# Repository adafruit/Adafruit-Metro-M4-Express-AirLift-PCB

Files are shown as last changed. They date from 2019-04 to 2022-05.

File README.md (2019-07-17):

## Adafruit Metro M4 Express AirLift (WiFi) - Lite PCB

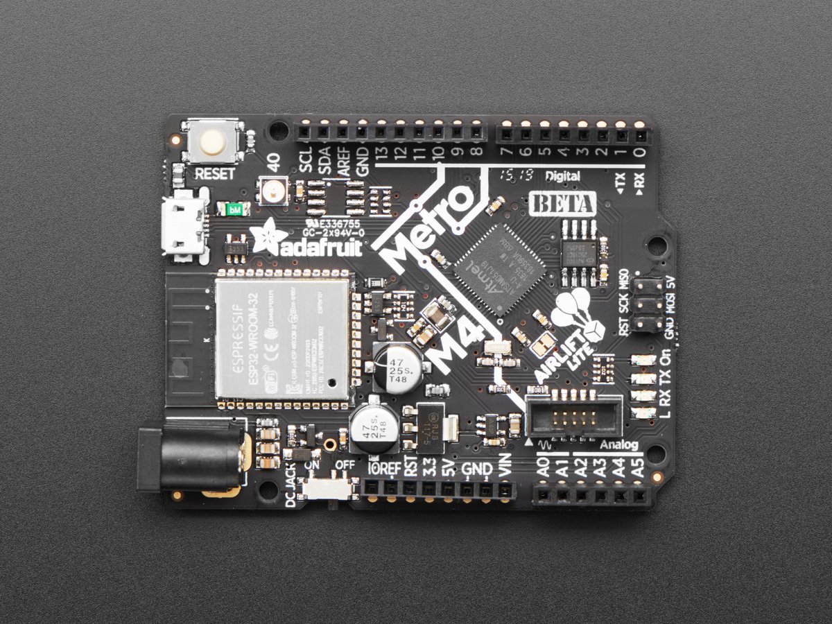
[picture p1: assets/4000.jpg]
<a href="http://www.adafruit.com/products/4000"><br/>
Click here to purchase one from the Adafruit shop</a>

PCB files for the Adafruit Metro M4 Express AirLift (WiFi) - Lite. 

Format is EagleCAD schematic and board layout
* https://www.adafruit.com/product/4000

### Description

Give your next project a lift with _AirLift_ - our witty name for the ESP32 co-processor that graces this Metro M4. You already know about the **Adafruit Metro M4** featuring the **Microchip ATSAMD51**, with it's 120MHz Cortex M4 with floating point support. With a train-load of FLASH and RAM, your code will be fast and roomy. And what better way to improve it than to add wireless? Now cooked in directly on board, you get a certified WiFi module that can handle all your TLS and socket needs, it even has root certificates pre-loaded.

This Metro is the same size as the others, and is compatible with all our shields. It's got analog pins where you expect, and SPI/UART/I2C hardware support in the same spot as the Metro 328 and M0. But! It's powered with an ATSAMD51J19:
 * Cortex M4 core running at **120 MHz**
 * [Floating point support with Cortex M4 DSP instructions](https://developer.arm.com/technologies/dsp/dsp-for-cortex-m)
 * **512 KB** flash, **192 KB** RAM
 * 32-bit, 3.3V logic and power
 * Dual 1 MSPS DAC (A0 and A1)
 * Dual 1 MSPS ADC (8 analog pins)
 * 6 x hardware SERCOM (I2C, SPI or UART)
 * 22 x PWM outputs
 * Stereo I2S input/output with MCK pin
 * 10-bit Parallel capture controller (for camera/video in)
 * Built in crypto engines with AES (256 bit), true RNG, Pubkey controller
 * 64 QFN

Pretty good start right? So we put this chip on a PCB with all these nice extras:
 * **Power the METRO M4** with 7-9V polarity protected DC or the micro USB connector to any 5V USB source. The 2.1mm DC jack has an on/off switch next to it so you can turn off your setup easily. The METRO will automagically switch between USB and DC.
 * **METRO has 25 GPIO** pins, 8 of which are analog in, and two of which is a true analog out. There's a hardware SPI port, hardware I2C port and hardware UART. Logic level is 3.3V
 * **Native USB**, there's no need for a hardware USB to Serial converter as the Metro M4 has built in USB support. When used to act like a serial device, the USB interface can be used by any computer to listen/send data to the METRO, and can also be used to launch and update code via the bootloader. It can also act like an HID keyboard or mouse.
 * **AirLift WiFi Co-processor**, with TLS/SSL support, plenty of RAM for sockets, communication is over SPI and has Arduino and CircuitPython libraries ready to go for fast wireless integration.
 * **Four indicator LEDs and one NeoPixel**, on the back edge of the PCB, for easy debugging. One green power LED, two RX/TX LEDs for data being sent over USB, and a red LED connected. Next to the reset button there is an RGB NeoPixel that can be used for any purpose.
 * **2 MB QSPI Flash** storage chip is included on board. You can use the SPI Flash storage like a very tiny hard drive. When used in Circuit Python, the 2 MB flash acts as storage for all your scripts, libraries and files. When used in Arduino, you can read/write files to it, like a little datalogger or SD card, and then with our helper program, access the files over USB.
 * **Easy reprogramming**, comes pre-loaded with the [UF2 bootloader](https://learn.adafruit.com/adafruit-metro-m0-express-designed-for-circuitpython/uf2-bootloader), which looks like a USB storage key. Simply drag firmware on to program, no special tools or drivers needed! It can be used to load up CircuitPython or Arduino IDE (it is bossa v1.8 compatible)
We have a working Arduino board support package, with lots of stuff working, but our primary target for this board is CircuitPython - with 120 MHz, and 192KB of RAM CircuitPython runs really well on this chip! CircuitPython's built in support for JSON parsing plus our requests compatible library makes it incredibly easy to build secure IoT projects in just a few minutes.

So what are you waiting for? Pick up a Metro M4 AirLift today and be amazed at how easy and fast it is to get started with IoT projects using CircuitPython!

### License

Adafruit invests time and resources providing this open source design, please support Adafruit and open-source hardware by purchasing products from [Adafruit](https://www.adafruit.com)!

Designed by Limor Fried/Ladyada for Adafruit Industries.

Creative Commons Attribution/Share-Alike, all text above must be included in any redistribution. 
See license.txt for additional details.

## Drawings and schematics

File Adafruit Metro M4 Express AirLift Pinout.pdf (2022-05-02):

# Adafruit Metro M4 AirLift Lite

# https://www.adafruit.com/product/4000

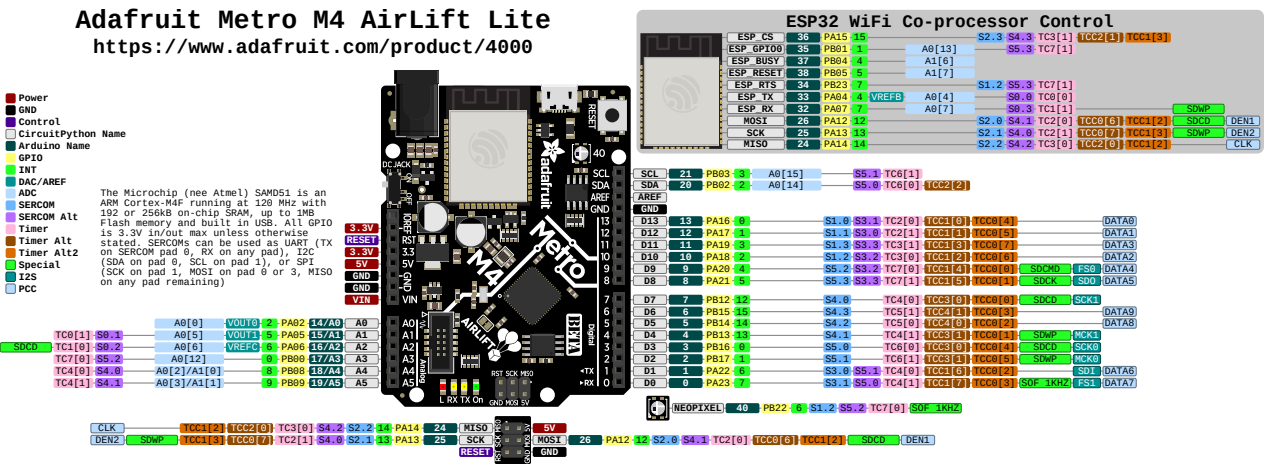
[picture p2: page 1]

ESP32 WiFi Co-processor Control

The Microchip (nee Atmel) SAMD51 is an
ARM Cortex-M4F running at 120 MHz with
192 or 256kB on-chip SRAM, up to 1MB
Flash memory and built in USB. All GPIO
is 3.3V in/out max unless otherwise
stated. SERCOMs can be used as UART (TX
on SERCOM pad 0, RX on any pad), I2C
(SDA on pad 0, SCL on pad 1), or SPI
(SCK on pad 1, MOSI on pad 0 or 3, MISO
on any pad remaining)

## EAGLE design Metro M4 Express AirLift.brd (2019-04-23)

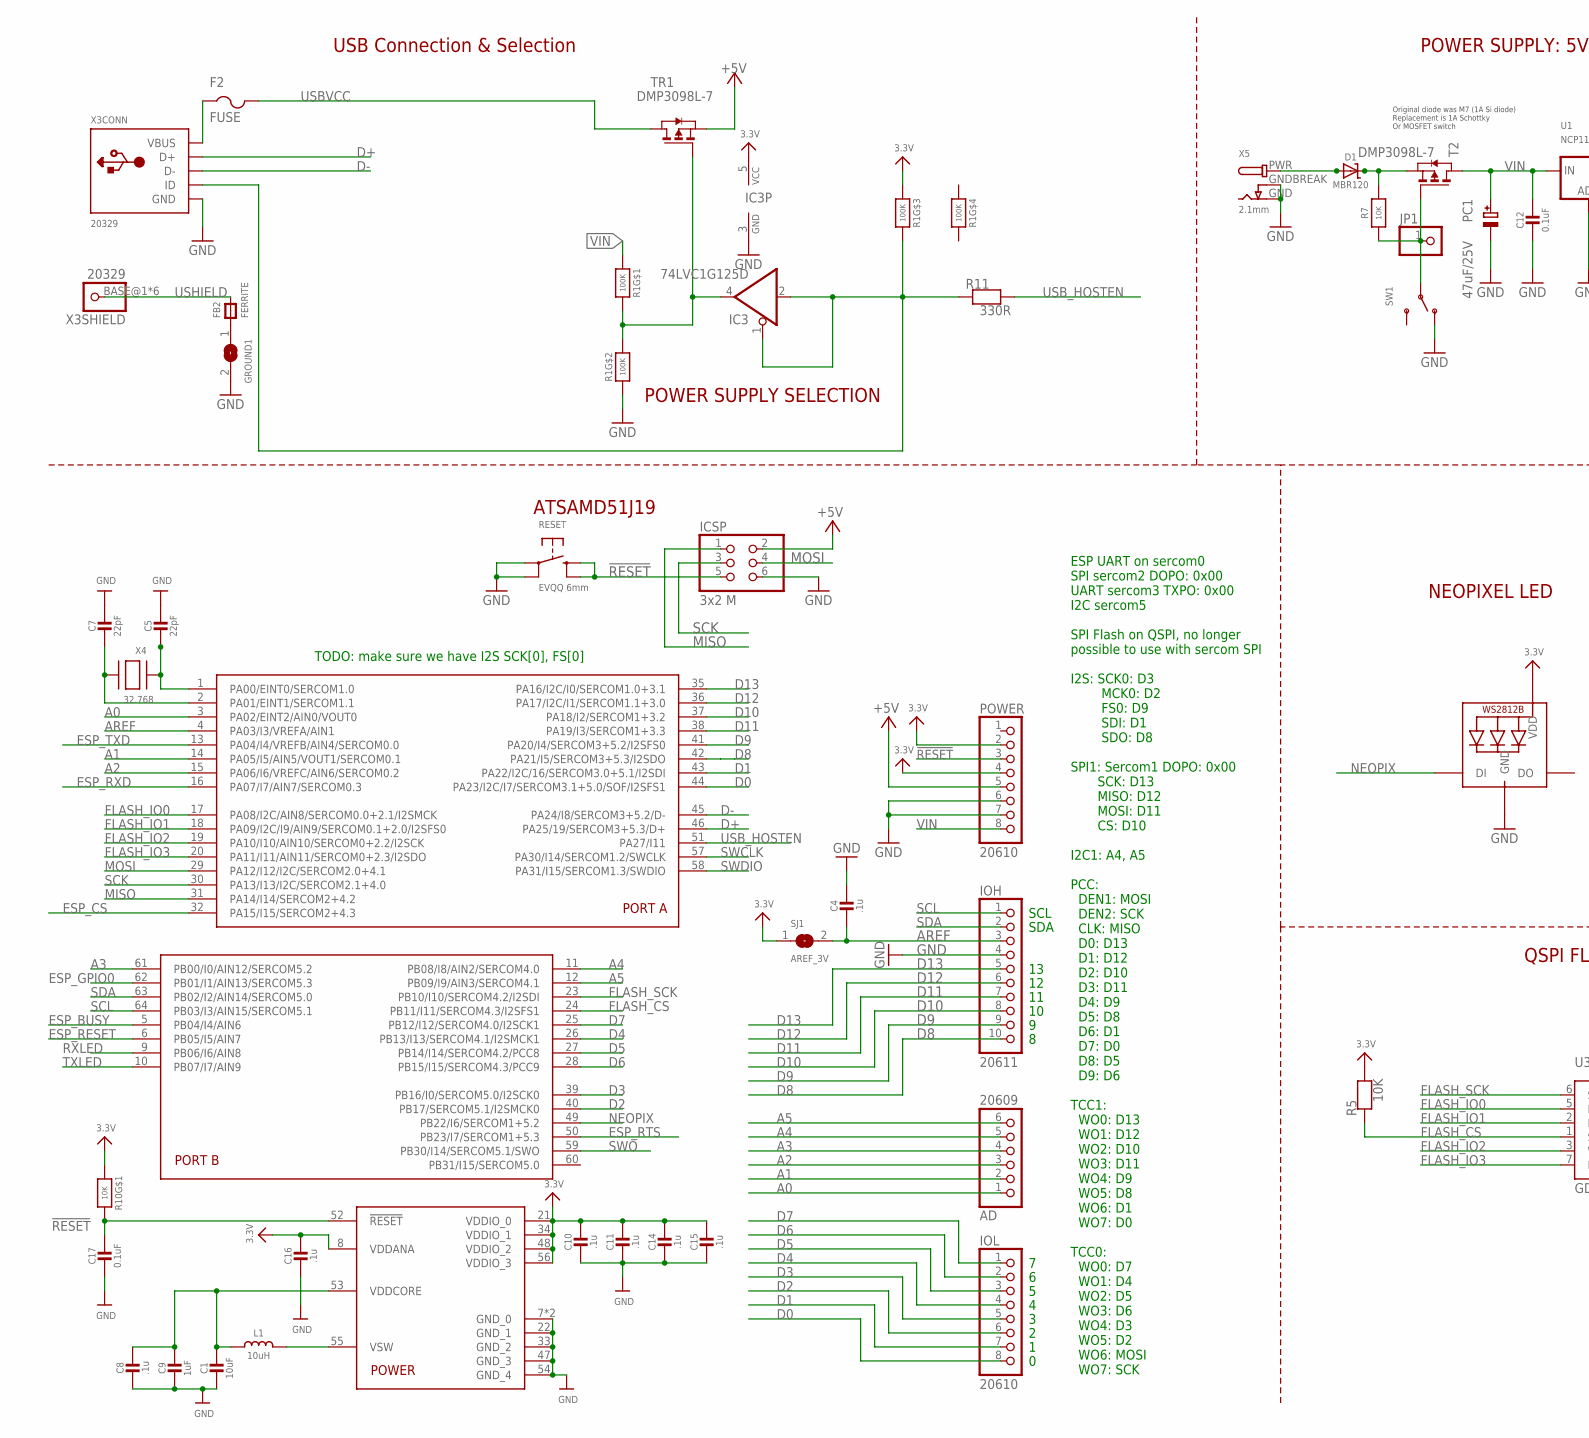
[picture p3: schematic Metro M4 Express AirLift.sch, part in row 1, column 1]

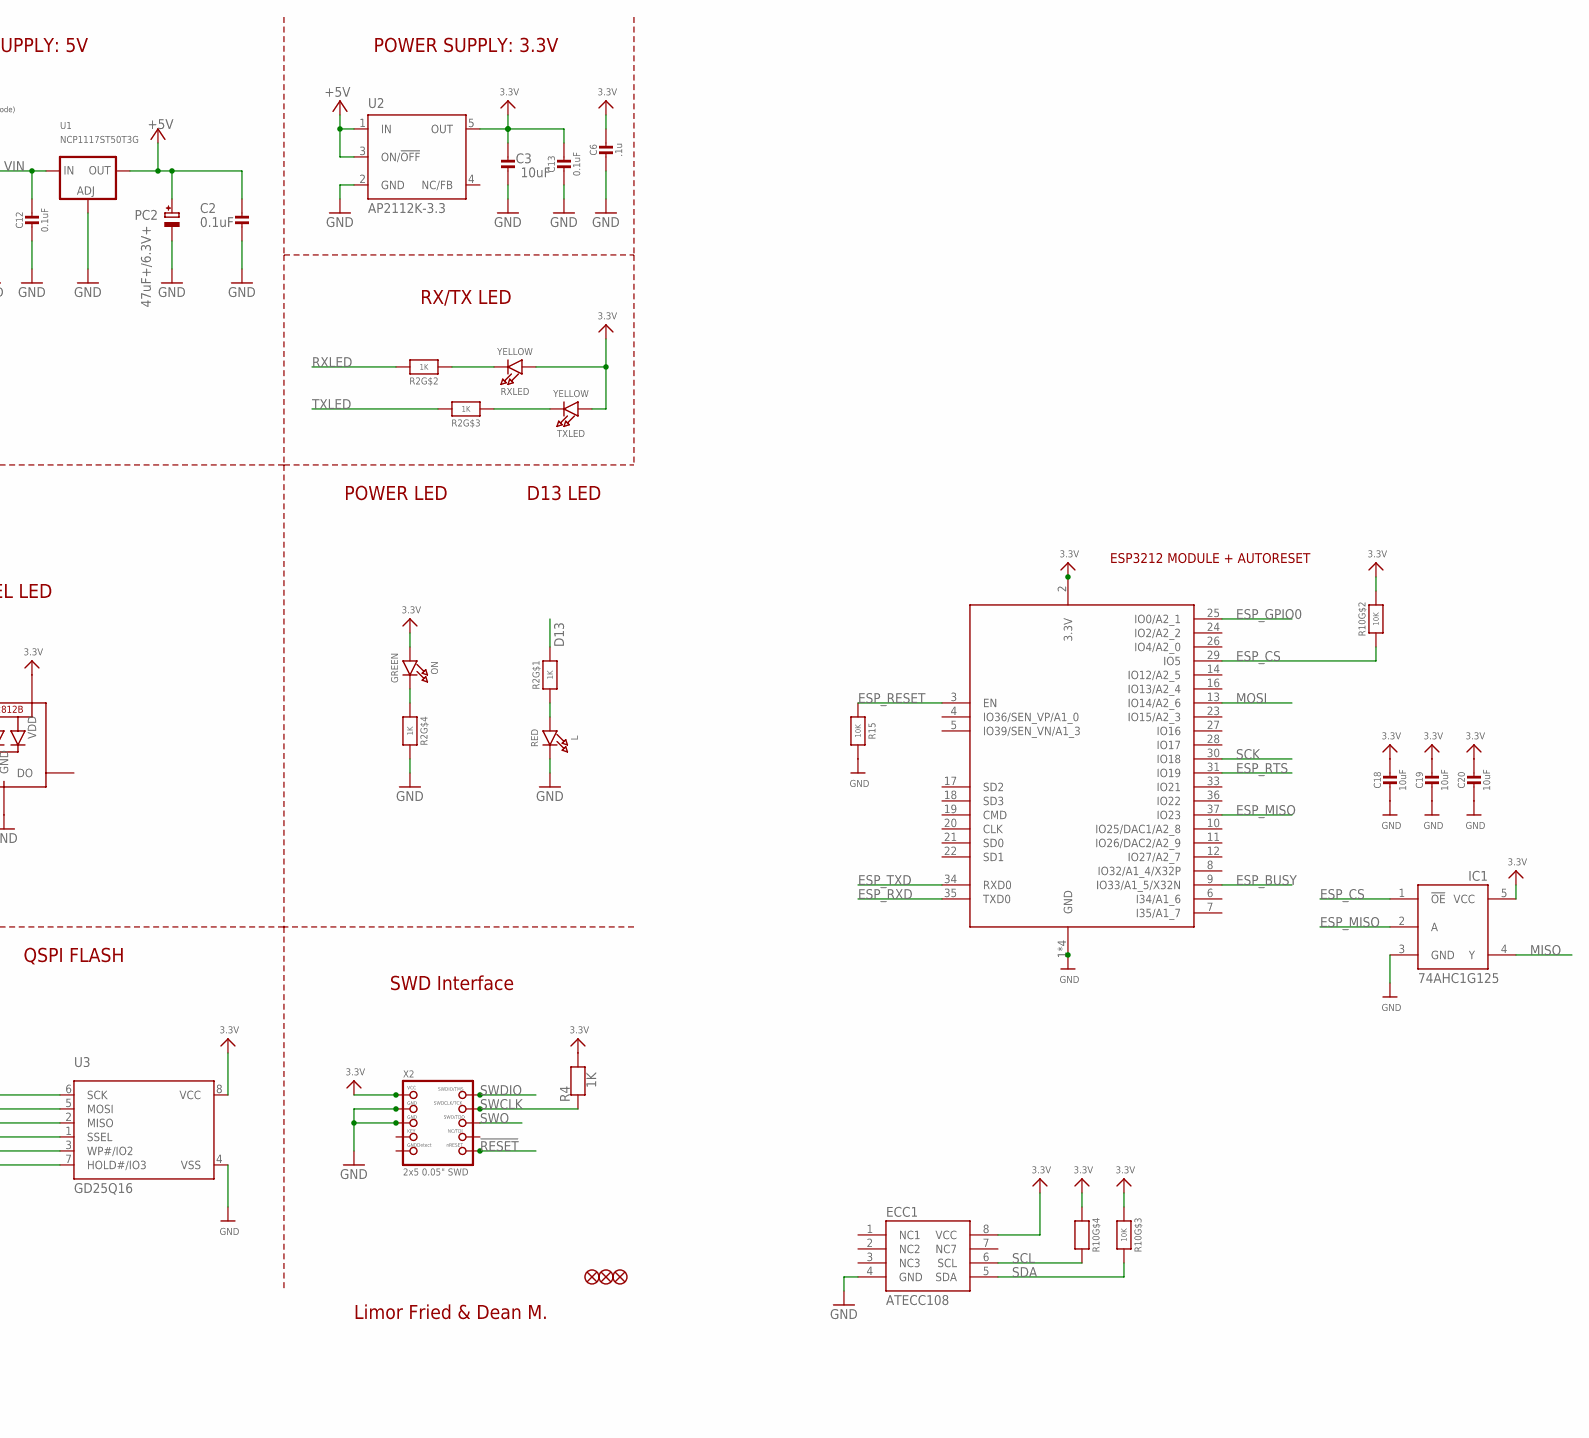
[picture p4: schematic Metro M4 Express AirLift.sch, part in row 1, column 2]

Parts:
AD: 20609; 1X06_OVALWAVE
C1, C3, C18, C19, C20: 10uF; 0805-NO
C2: 0.1uF; 0805-NO
C4, C6, C8, C10, C11, C14, C15, C16: .1u; 0603-NO
C5, C7: 22pF; 0603-NO
C9: 1uF; 0603-NO
C12, C13, C17: 0.1uF; 0603-NO
D1: MBR120; SOD-123
ECC1: ATECC108; SOIC8
F2: FUSE; R1206
FB2: FERRITE; 0805-NO
FD1, FD2, FD3: FIDUCIAL_1MM
GROUND1: SOLDERJUMPERCLOSED; SOLDERJUMPER_CLOSEDWIRE
IC1: 74AHC1G125; SOT23-5L
IC3: 74LVC1G125D; SOT23-5
ICSP: 3x2 M; 2X03_ROUND_70MIL
IOH: 20611; 1X10_OVALWAVE
IOL: 20610; 1X08_OVALWAVE
JP1: HEADER-1X1ROUND; 1X01_ROUND
L: RED; CHIPLED_0805_NOOUTLINE
L1: 10uH; INDUCTOR_1007
LED1: WS2812B3535; LED3535
ON: GREEN; CHIPLED_0805_NOOUTLINE
PC1: 47uF/25V; PANASONIC_D
PC2: 47uF+/6.3V+; PANASONIC_D
POWER: 20610; 1X08_OVALWAVE
R1: 100K; RESPACK_4X0603
R2: 1K; RESPACK_4X0603
R4: 1K; 0603-NO
R5, R7, R15: 10K; 0603-NO
R10: 10K; RESPACK_4X0603
R11: 330R; 0603-NO
RESET: EVQQ 6mm; EVQ-Q2_SMALLER
RXLED: YELLOW; CHIPLED_0805_NOOUTLINE
SJ1: AREF_3V; SOLDERJUMPER_CLOSEDWIRE
SW1: SWITCH_SPDT; SPDT_SMT_SSSS811101
T2: DMP3098L-7; SOT-23
TR1: DMP3098L-7; SOT-23
TXLED: YELLOW; CHIPLED_0805_NOOUTLINE
U1: NCP1117ST50T3G; SOT223-R
U2: AP2112K-3.3; SOT23-DBV
U3: GD25Q16; SOIC8_208MIL
U$1: ATSAMD51J19; PQFN64-1
X2: 2x5 0.05" SWD; 2X05_1.27MM_BOX_POSTS
X3: 20329; 4UCONN_20329_V2
X4: 32.768; XTAL3215
X5: 2.1mm; DCJACK_2MM_PTH
X6: ESP32_WROOM32; WROOM32

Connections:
3.3V: C3.2, C6.2, C10.2, C11.2, C13.1, C14.2, C15.2, C16.2, C18.1, C19.1, C20.1, ECC1.8 (VCC), IC1.5 (VCC), IC3.5 (VCC), LED1.2 (VDD), ON.A, POWER.2, POWER.4, R1.3 (1), R4.2, R5.2, R10.1, R10.3 (1), R10.4 (1), R10.7 (2), RXLED.A, SJ1.1, TXLED.A, U2.5 (OUT), U3.8 (VCC), U$1.8 (VDDANA), U$1.21 (VDDIO_0), U$1.34 (VDDIO_1), U$1.48 (VDDIO_2), U$1.56 (VDDIO_3), X2.1 (VCC), X6.2 (3.3V)
!RESET: C17.2, ICSP.5, POWER.3, R10.8 (2), RESET.B (S), RESET.B' (S1), U$1.52 (!RESET), X2.10 (NRESET)
+5V: C2.2, ICSP.2, PC2.+, POWER.5, TR1.2 (S), U1.2 (OUT), U1.4 (OUT), U2.1 (IN), U2.3 (ON/!OFF)
A0: AD.1, U$1.3 (PA02/EINT2/AIN0/VOUT0)
A1: AD.2, U$1.14 (PA05/I5/AIN5/VOUT1/SERCOM0.1)
A2: AD.3, U$1.15 (PA06/I6/VREFC/AIN6/SERCOM0.2)
A3: AD.4, U$1.61 (PB00/I0/AIN12/SERCOM5.2)
A4: AD.5, U$1.11 (PB08/I8/AIN2/SERCOM4.0)
A5: AD.6, U$1.12 (PB09/I9/AIN3/SERCOM4.1)
AREF: C4.1, IOH.3, SJ1.2, U$1.4 (PA03/I3/VREFA/AIN1)
D0: IOL.8, U$1.44 (PA23/I2C/I7/SERCOM3.1+5.0/SOF/I2SFS1)
D1: IOL.7, U$1.43 (PA22/I2C/16/SERCOM3.0+5.1/I2SDI)
D2: IOL.6, U$1.40 (PB17/SERCOM5.1/I2SMCK0)
D3: IOL.5, U$1.39 (PB16/I0/SERCOM5.0/I2SCK0)
D4: IOL.4, U$1.26 (PB13/I13/SERCOM4.1/I2SMCK1)
D5: IOL.3, U$1.27 (PB14/I14/SERCOM4.2/PCC8)
D6: IOL.2, U$1.28 (PB15/I15/SERCOM4.3/PCC9)
D7: IOL.1, U$1.25 (PB12/I12/SERCOM4.0/I2SCK1)
D8: IOH.10, U$1.42 (PA21/I5/SERCOM3+5.3/I2SDO)
D9: IOH.9, U$1.41 (PA20/I4/SERCOM3+5.2/I2SFS0)
D10: IOH.8, U$1.37 (PA18/I2/SERCOM1+3.2)
D11: IOH.7, U$1.38 (PA19/I3/SERCOM1+3.3)
D12: IOH.6, U$1.36 (PA17/I2C/I1/SERCOM1.1+3.0)
D13: IOH.5, R2.8 (2), U$1.35 (PA16/I2C/I0/SERCOM1.0+3.1)
D+: U$1.46 (PA25/19/SERCOM3+5.3/D+), X3.D+
D-: U$1.45 (PA24/I8/SERCOM3+5.2/D-), X3.D-
ESP_BUSY: U$1.5 (PB04/I4/AIN6), X6.9 (IO33/A1_5/X32N)
ESP_CS: IC1.1 (!OE), R10.2 (1), U$1.32 (PA15/I15/SERCOM2+4.3), X6.29 (IO5)
ESP_GPIO0: U$1.62 (PB01/I1/AIN13/SERCOM5.3), X6.25 (IO0/A2_1)
ESP_MISO: IC1.2 (A), X6.37 (IO23)
ESP_RESET: R15.1, U$1.6 (PB05/I5/AIN7), X6.3 (EN)
ESP_RTS: U$1.50 (PB23/I7/SERCOM1+5.3), X6.31 (IO19)
ESP_RXD: U$1.16 (PA07/I7/AIN7/SERCOM0.3), X6.35 (TXD0)
ESP_TXD: U$1.13 (PA04/I4/VREFB/AIN4/SERCOM0.0), X6.34 (RXD0)
FLASH_CS: R5.1, U3.1 (SSEL), U$1.24 (PB11/I11/SERCOM4.3/I2SFS1)
FLASH_IO0: U3.5 (MOSI), U$1.17 (PA08/I2C/AIN8/SERCOM0.0+2.1/I2SMCK)
FLASH_IO1: U3.2 (MISO), U$1.18 (PA09/I2C/I9/AIN9/SERCOM0.1+2.0/I2SFS0)
FLASH_IO2: U3.3 (WP#/IO2), U$1.19 (PA10/I10/AIN10/SERCOM0+2.2/I2SCK)
FLASH_IO3: U3.7 (HOLD#/IO3), U$1.20 (PA11/I11/AIN11/SERCOM0+2.3/I2SDO)
FLASH_SCK: U3.6 (SCK), U$1.23 (PB10/I10/SERCOM4.2/I2SDI)
GND: C1.2, C2.1, C3.1, C4.2, C5.2, C6.1, C7.2, C8.1, C9.2, C10.1, C11.1, C12.2, C13.2, C14.1, C15.1, C16.1, C17.1, C18.2, C19.2, C20.2, ECC1.4 (GND), GROUND1.2, IC1.3 (GND), IC3.3 (GND), ICSP.6, IOH.4, L.C, LED1.4 (GND), PC1.-, PC2.-, POWER.6, POWER.7, R1.2 (1), R2.5 (2), R15.2, RESET.A, RESET.A' (P1), SW1.A (O), U1.1 (ADJ), U2.2 (GND), U3.4 (VSS), U$1.7 (GND_0), U$1.22 (GND_1), U$1.33 (GND_2), U$1.47 (GND_3), U$1.54 (GND_4), U$1.EXP (GND_0), X2.3 (GND), X2.5 (GND), X3.GND, X5.GND, X5.GNDBREAK, X6.1 (GND), X6.15 (GND), X6.38 (GND), X6.P$1 (GND)
MISO: IC1.4 (Y), ICSP.1, U$1.31 (PA14/I14/SERCOM2+4.2)
MOSI: ICSP.4, U$1.29 (PA12/I12/I2C/SERCOM2.0+4.1), X6.13 (IO14/A2_6)
unnamed: L.A, R2.1
unnamed: FB2.1, GROUND1.1
unnamed: ON.C, R2.4 (1)
unnamed: L1.P$2 (2), U$1.55 (VSW)
unnamed: R2.2 (1), RXLED.C
unnamed: R2.3 (1), TXLED.C
unnamed: C5.1, U$1.1 (PA00/EINT0/SERCOM1.0), X4.P$1
unnamed: IC3.1 (OE), IC3.2 (I), R1.6 (2), R11.1, X3.ID
unnamed: IC3.4 (O), R1.7 (2), R1.8 (2), TR1.3 (G)
unnamed: C7.1, U$1.2 (PA01/EINT1/SERCOM1.1), X4.P$2
unnamed: D1.C, R7.2, T2.2 (S)
NEOPIX: LED1.1 (DI), U$1.49 (PB22/I6/SERCOM1+5.2)
PWRIN: D1.A, X5.PWR
PWR_SWITCH: JP1.1, R7.1, SW1.B, T2.3 (G)
RXLED: R2.7 (2), U$1.9 (PB06/I6/AIN8)
SCK: ICSP.3, U$1.30 (PA13/I13/I2C/SERCOM2.1+4.0), X6.30 (IO18)
SCL: ECC1.6 (SCL), IOH.1, R10.5 (2), U$1.64 (PB03/I3/AIN15/SERCOM5.1)
SDA: ECC1.5 (SDA), IOH.2, R10.6 (2), U$1.63 (PB02/I2/AIN14/SERCOM5.0)
SWCLK: R4.1, U$1.57 (PA30/I14/SERCOM1.2/SWCLK), X2.4 (SWDCLK)
SWDIO: U$1.58 (PA31/I15/SERCOM1.3/SWDIO), X2.2 (SWDIO)
SWO: U$1.59 (PB30/I14/SERCOM5.1/SWO), X2.6 (SWO)
TXLED: R2.6 (2), U$1.10 (PB07/I7/AIN9)
USBVCC: F2.2, TR1.1 (D)
USB_HOSTEN: R11.2, U$1.51 (PA27/I11)
USHIELD: FB2.2, X3.BASE@1 (1), X3.BASE@2 (1), X3.SPRT@1 (1), X3.SPRT@2 (1), X3.SPRT@3 (1), X3.SPRT@4 (1)
VBUS: F2.1, X3.VBUS
VDDCORE: C1.1, C8.2, C9.1, L1.P$1 (1), U$1.53 (VDDCORE)
VIN: C12.1, PC1.+, POWER.8, R1.1, T2.1 (D), U1.3 (IN)

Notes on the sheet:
SDA
SCL
Limor Fried & Dean M.
Original diode was M7 (1A Si diode) Replacement is 1A Schottky Or MOSFET switch
POWER SUPPLY: 5V
USB Connection & Selection
POWER SUPPLY: 3.3V
POWER LED
ATSAMD51J19
POWER SUPPLY SELECTION
D13 LED
RX/TX LED
NEOPIXEL LED
QSPI FLASH
SWD Interface
ESP UART on sercom0 SPI sercom2 DOPO: 0x00 UART sercom3 TXPO: 0x00 I2C sercom5 SPI Flash on QSPI, no longer possible to use with sercom SPI I2S: SCK0: D3 MCK0: D2 FS0: D9 SDI: D1 SDO: D8 SPI1: Sercom1 DOPO: 0x00 SCK: D13 MISO: D12 MOSI: D11 CS: D10 I2C1: A4, A5 PCC: DEN1: MOSI DEN2: SCK CLK: MISO D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
TODO: make sure we have I2S SCK[0], FS[0]
ESP3212 MODULE + AUTORESET

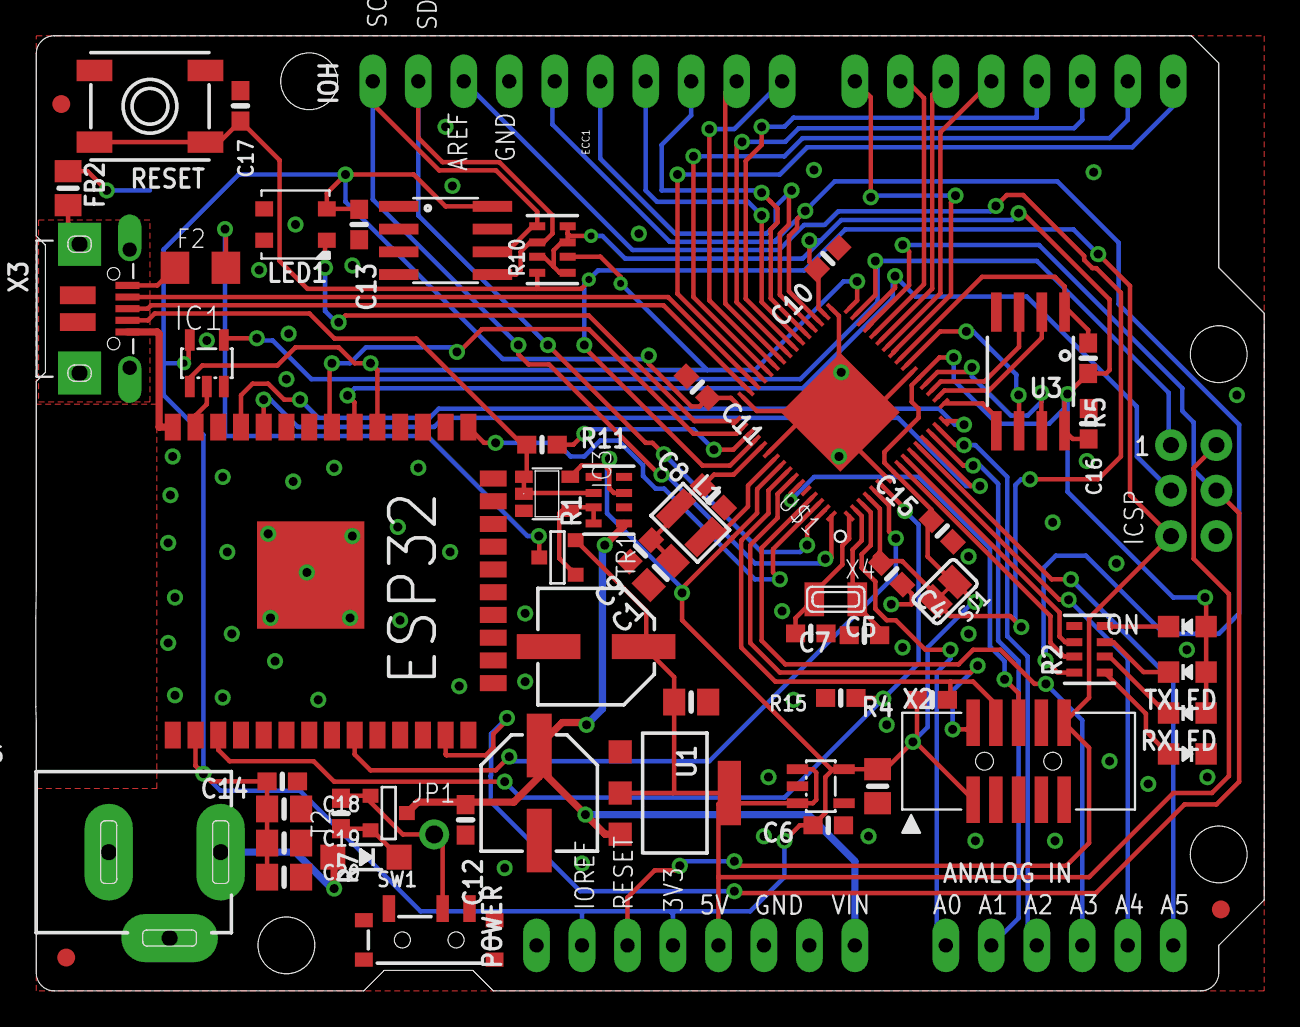
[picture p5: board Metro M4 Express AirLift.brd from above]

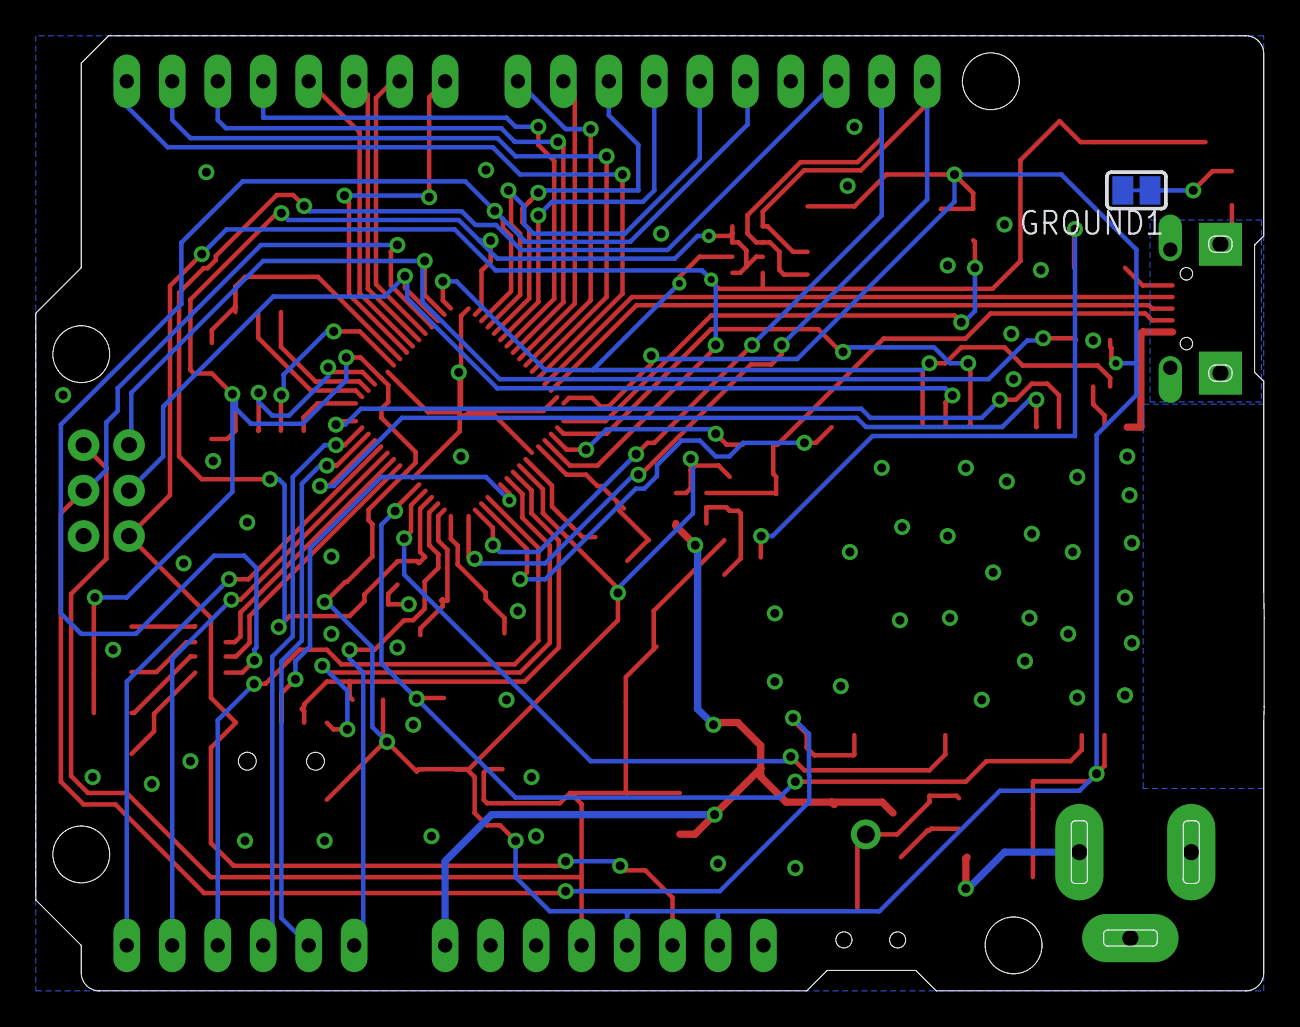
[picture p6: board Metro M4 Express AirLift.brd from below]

Board: 2 copper layers, 68.6 x 53.3 mm, 68 parts (2 on the bottom side), 71 nets.

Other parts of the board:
U$27: METROM4_AIRLIFT_LITE_BOT
U$39: METROM4_AIRLIFT_LITE_TOP

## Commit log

2019-04-23 Add board files
    [Metro M4 Express AirLift.brd, Metro M4 Express AirLift.sch]
2019-07-17 updated to use cookiecutter for pcb repos

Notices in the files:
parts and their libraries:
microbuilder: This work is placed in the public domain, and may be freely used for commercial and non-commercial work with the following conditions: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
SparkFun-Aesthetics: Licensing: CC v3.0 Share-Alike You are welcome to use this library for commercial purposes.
